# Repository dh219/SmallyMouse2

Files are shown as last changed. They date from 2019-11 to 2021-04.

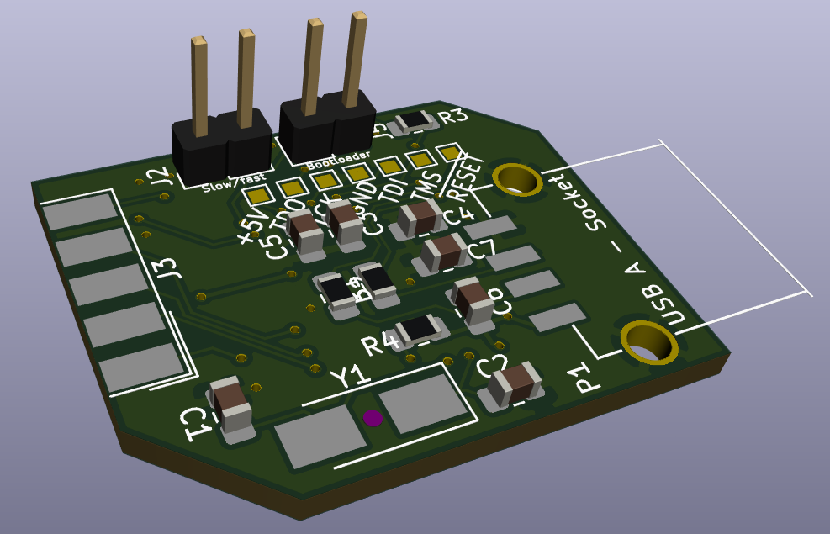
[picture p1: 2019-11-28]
Smalliermouse/images/smallier_board2.png

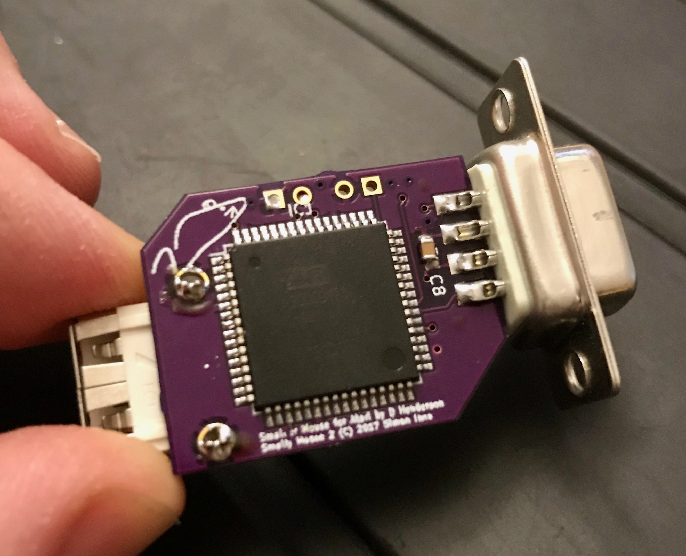
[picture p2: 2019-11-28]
Smalliermouse/images/smallier_complete1.jpg

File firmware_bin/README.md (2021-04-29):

## Binary Firmwares

These firmwares are provided as-is with no warranty or support offered. They may be of use if you don't want, or can't install the (Windows only) Atmel Studio to flash your SmallyMouse variant. They ought to be usable with the AVRDude software, available for many platforms, but please note I HAVE NOT tested this.

## Versions

All versions fix the potentially dangerous (on Atari STs) bug where the AT90 chip drives the button lines high when not in use by switching the lines to input (high-Z) when a button is in the 'up' position.

Low speed movement when a has been greatly enhanced when the DPI Division logic is enabled.

A change of direction lag bug has been fixed upstream.

## Jumper meaning change (from 1.0)

The J2 jumper, which previously set rate limiting on the qudrature output now configures whether the DPI Division logic should be use at all.

J2 connected will divide down the movement of the USB mouse. J2 disconnected will pass though all USB movement directly.

### DPI_DIV_3

This version uses a 1/3 multiplier on each USB mouse movement report to compensate for the much higher DPI rating of modern mice. This ratio is configurable in the firmware by setting the DPISCALE parameter. This parameter indicates the denominator in use. 3 => divide by 3.

### DPI_DIV_2

This version is as above, but uses a 1/2 multiplier.

D Henderson 2021.

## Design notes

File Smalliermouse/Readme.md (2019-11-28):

## Synopsis

Smalliermouse is a variation of SmallyMouse2 by D Henderson specificially designed for the Atari ST & Falcon to fit within the keyboard mouse plug bay.

## Motivation

USB plugs for modern (and particularly wireless) devices are so small theses days that, buy reducing the SmallyMouse2 footprint to its bare minimum would allow the entire mouse emulator to fit within the below-keyboard recess of the Atari ST range of computers.

## Installation

Note: This is an Atmel Studio 7 project that can be loaded and compiled by the IDE

Please see http://www.waitingforfriday.com/?p=827 for detailed documentation about SmallyMouse2

## Author

SmallyMouse2 is written and maintained by Simon Inns. Smalliermouse, upon which it is based remains (C) Simon Inns with modifications by D Henderson 2019.

## License (Software)

    SmallyMouse2 is free software: you can redistribute it and/or modify
    it under the terms of the GNU General Public License as published by
    the Free Software Foundation, either version 3 of the License, or
    (at your option) any later version.

    SmallyMouse2 is distributed in the hope that it will be useful,
    but WITHOUT ANY WARRANTY; without even the implied warranty of
    MERCHANTABILITY or FITNESS FOR A PARTICULAR PURPOSE.  See the
    GNU General Public License for more details.

    You should have received a copy of the GNU General Public License
    along with SmallyMouse2. If not, see <http://www.gnu.org/licenses/>.

## License (Hardware)

Both the schematic and the PCB design of SmallyMouse2 (i.e. the KiCAD project and files) are covered by a Creative Commons license; as with the software you are welcome (and encouraged!) to extend, re-spin and otherwise use and modify the design as allowed by the license.  However; under the terms of the Attribution-ShareAlike 4.0 International (CC BY-SA 4.0) license you are required to release your design (or redesign) under the same license.  For details of the licensing requirements please see <https://creativecommons.org/licenses/by-sa/4.0/>

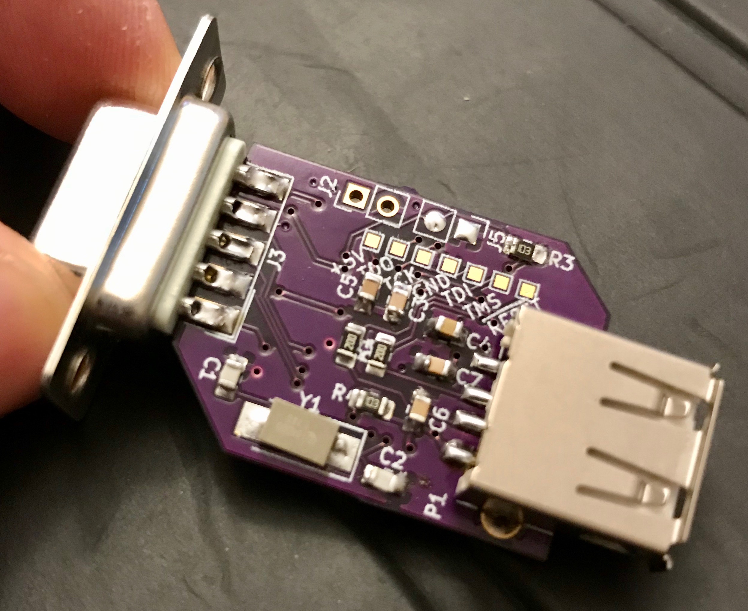
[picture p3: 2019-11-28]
Smalliermouse/images/smallier_complete2.jpg

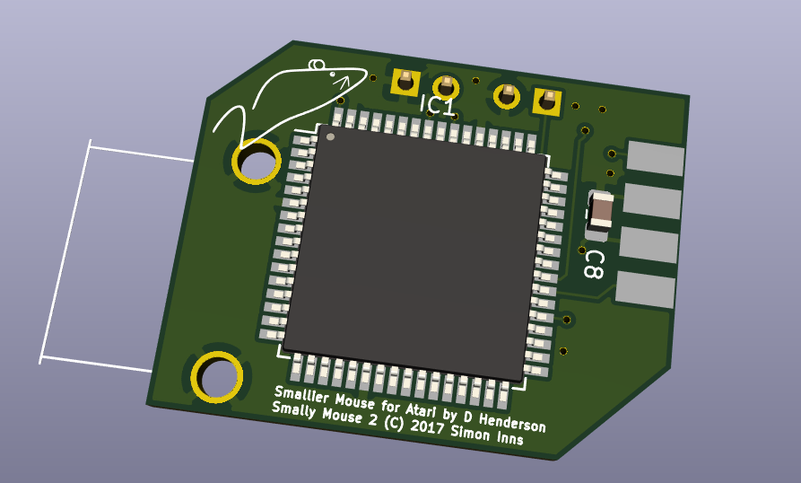
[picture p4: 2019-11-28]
Smalliermouse/images/smallier_board1.png

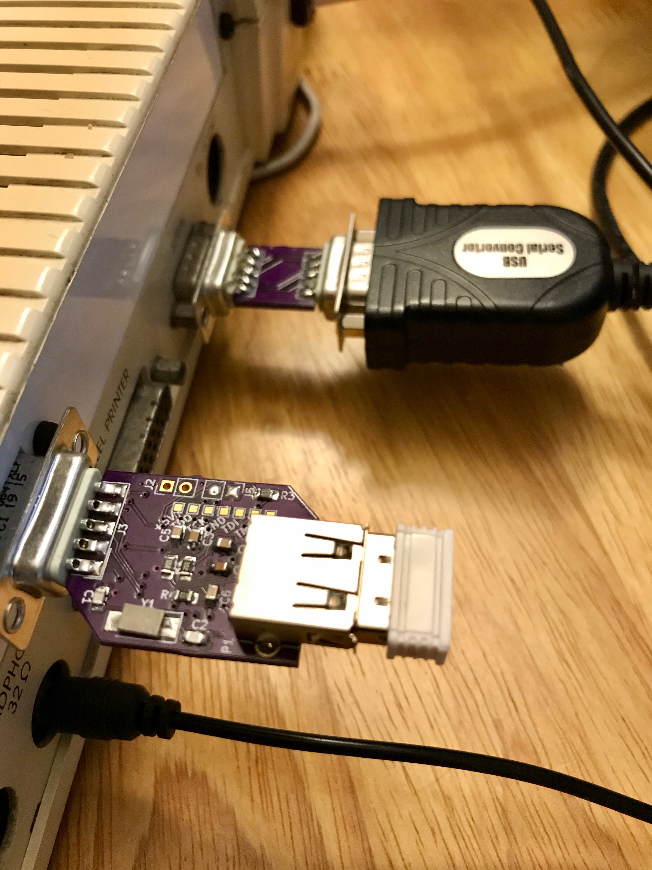
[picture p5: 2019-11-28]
Smalliermouse/images/smallier_insitu_acorn.jpg

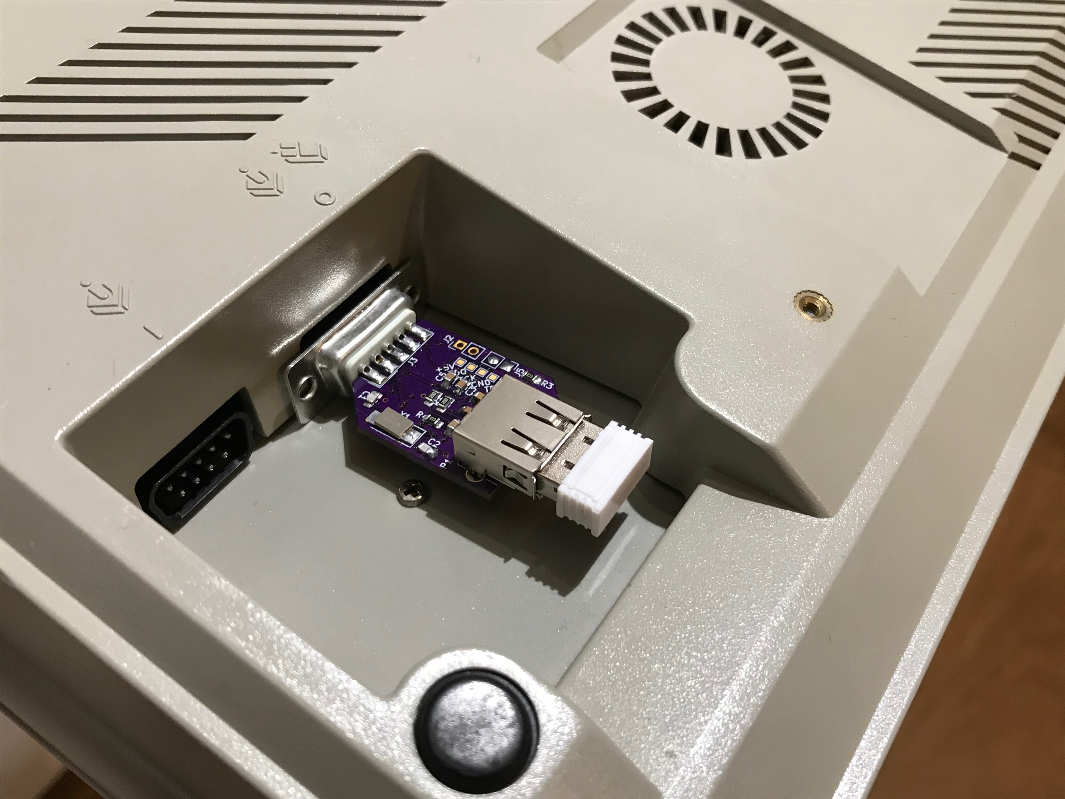
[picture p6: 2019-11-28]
Smalliermouse/images/smallier_insitu_falcon.jpg

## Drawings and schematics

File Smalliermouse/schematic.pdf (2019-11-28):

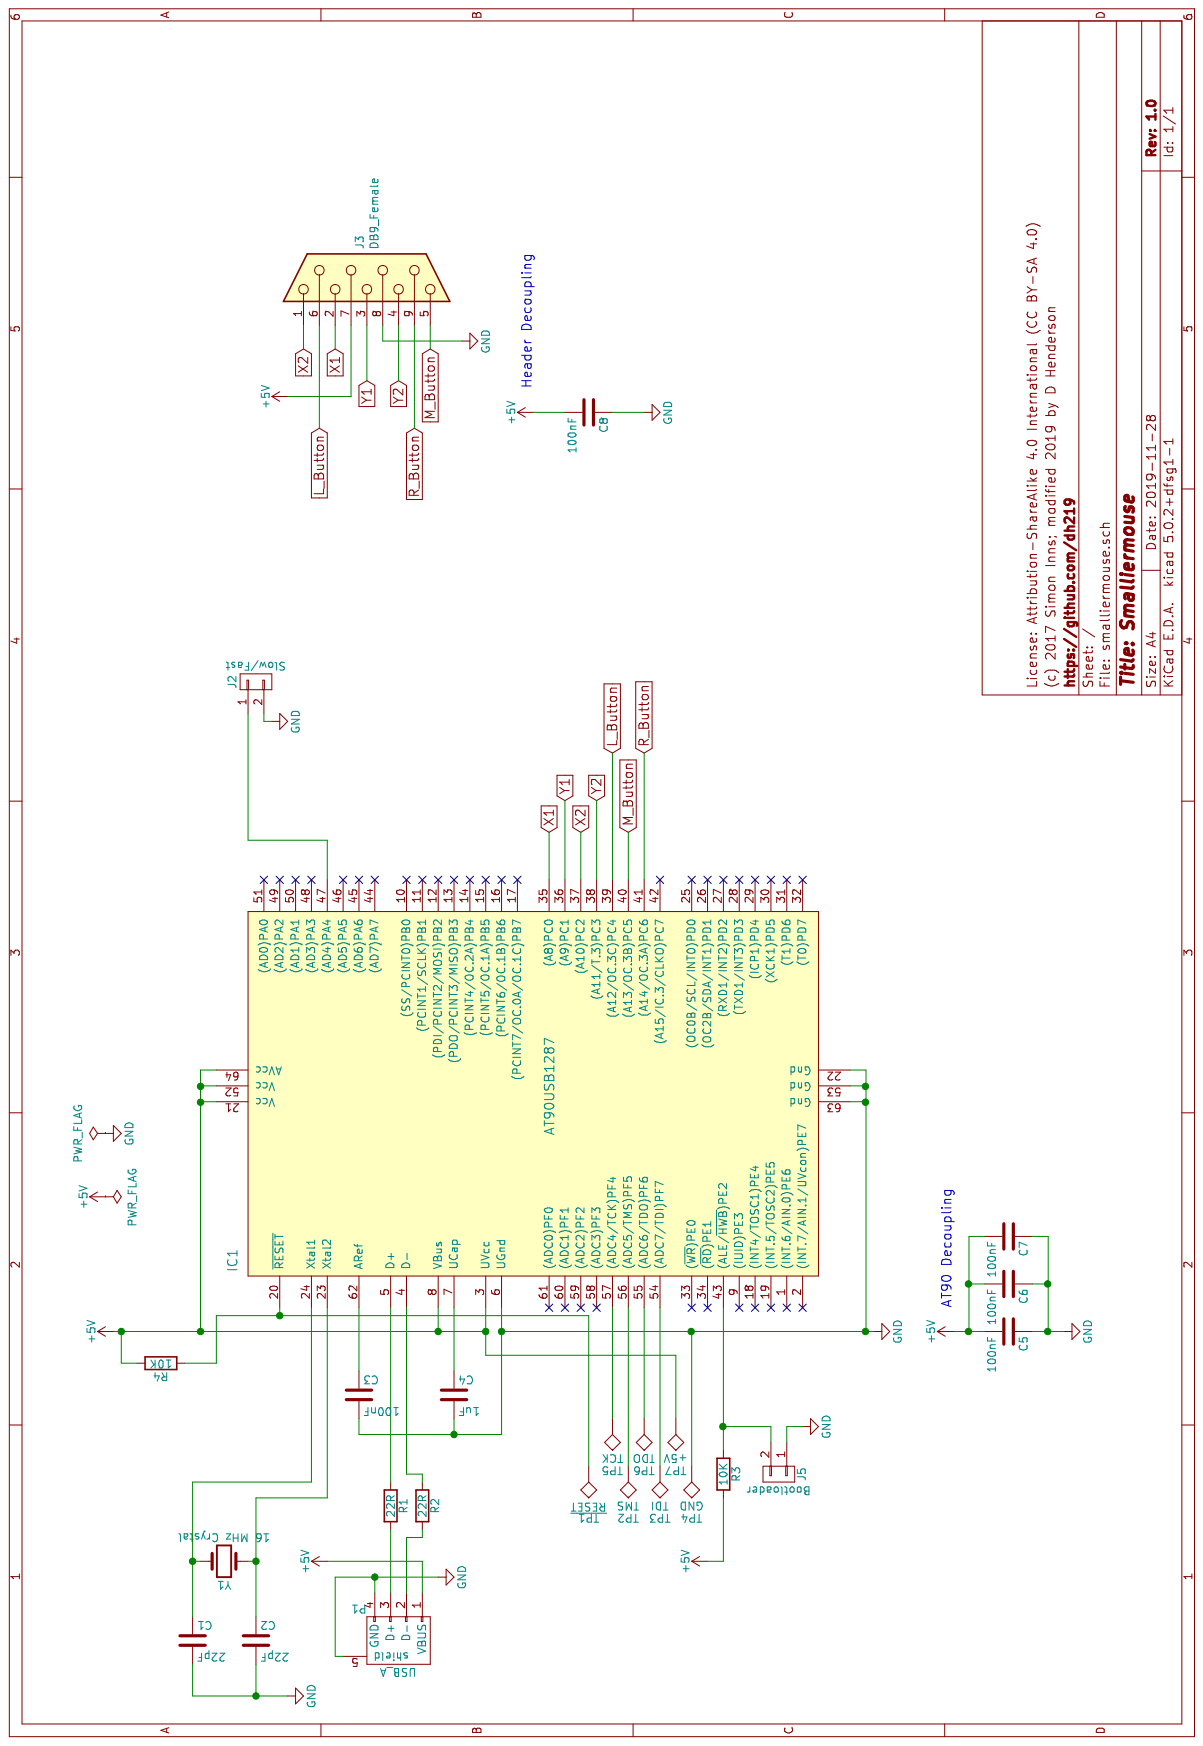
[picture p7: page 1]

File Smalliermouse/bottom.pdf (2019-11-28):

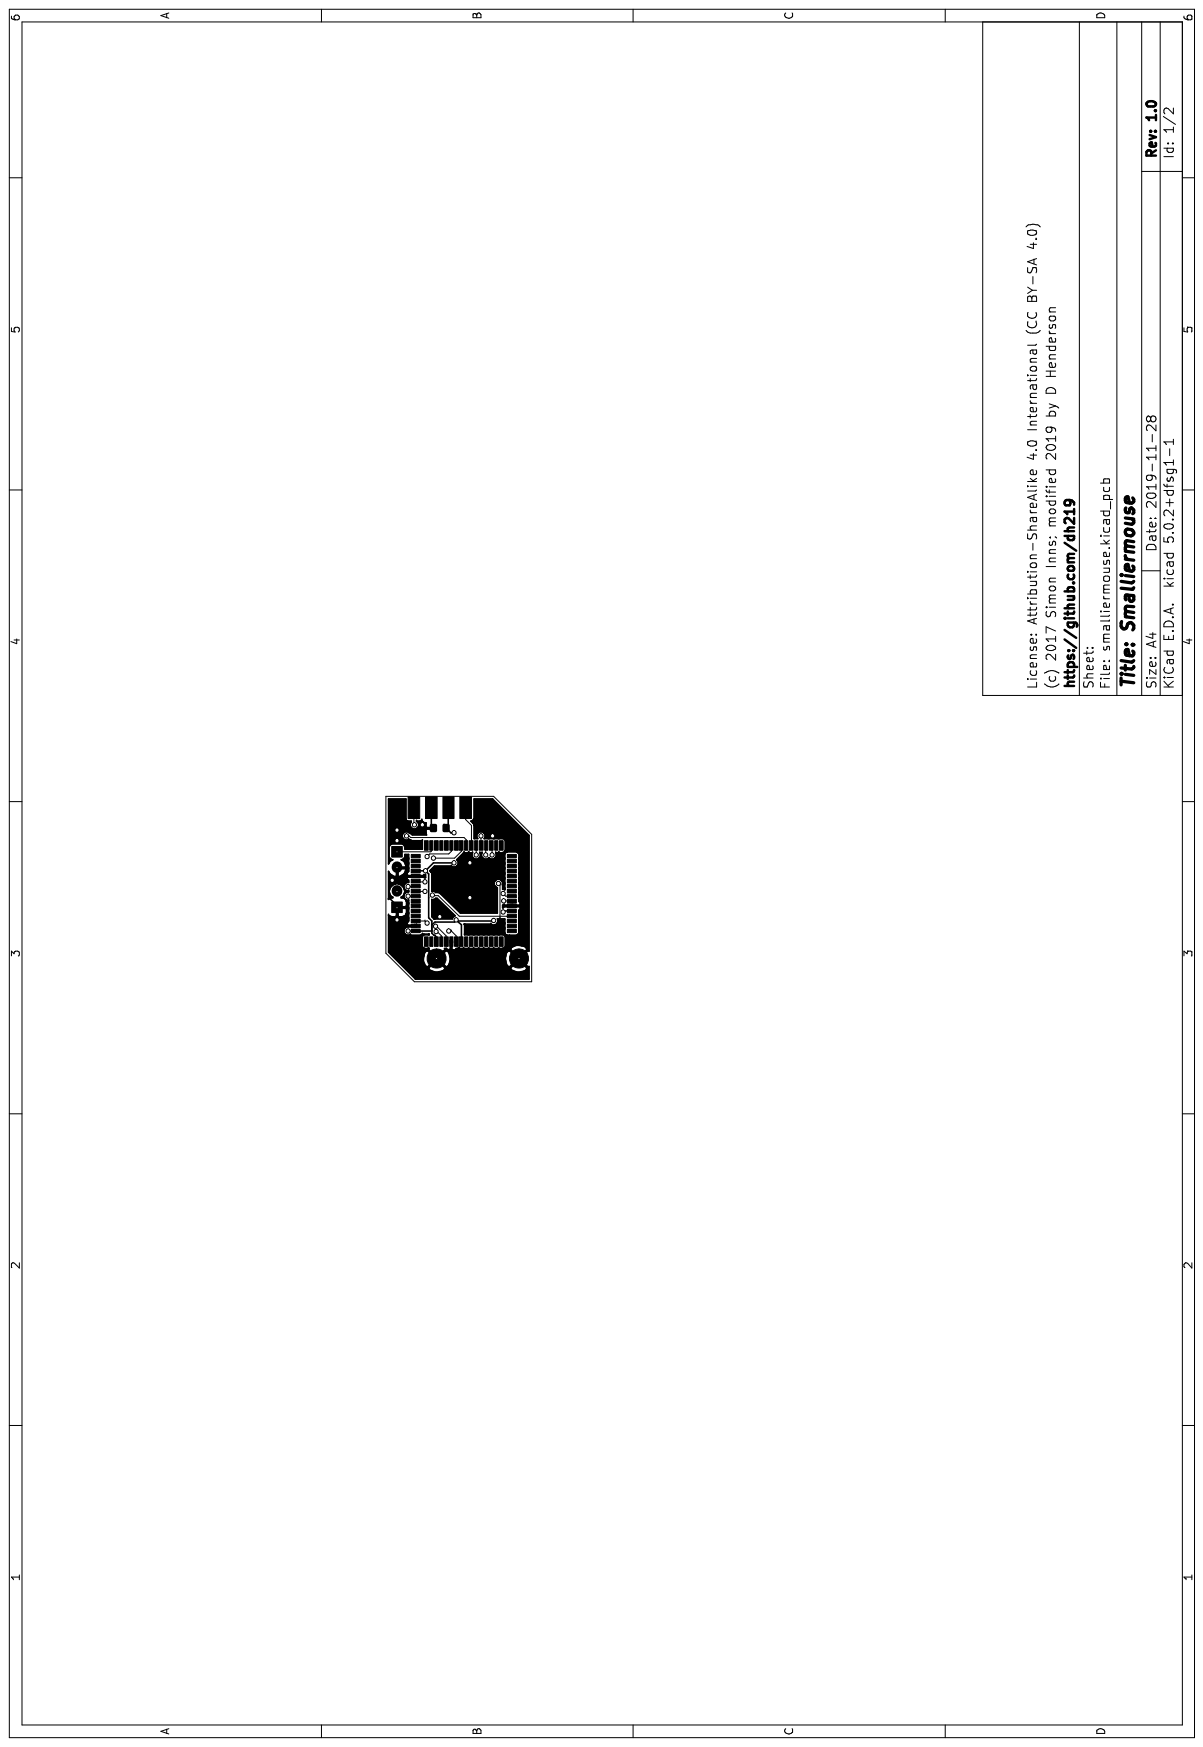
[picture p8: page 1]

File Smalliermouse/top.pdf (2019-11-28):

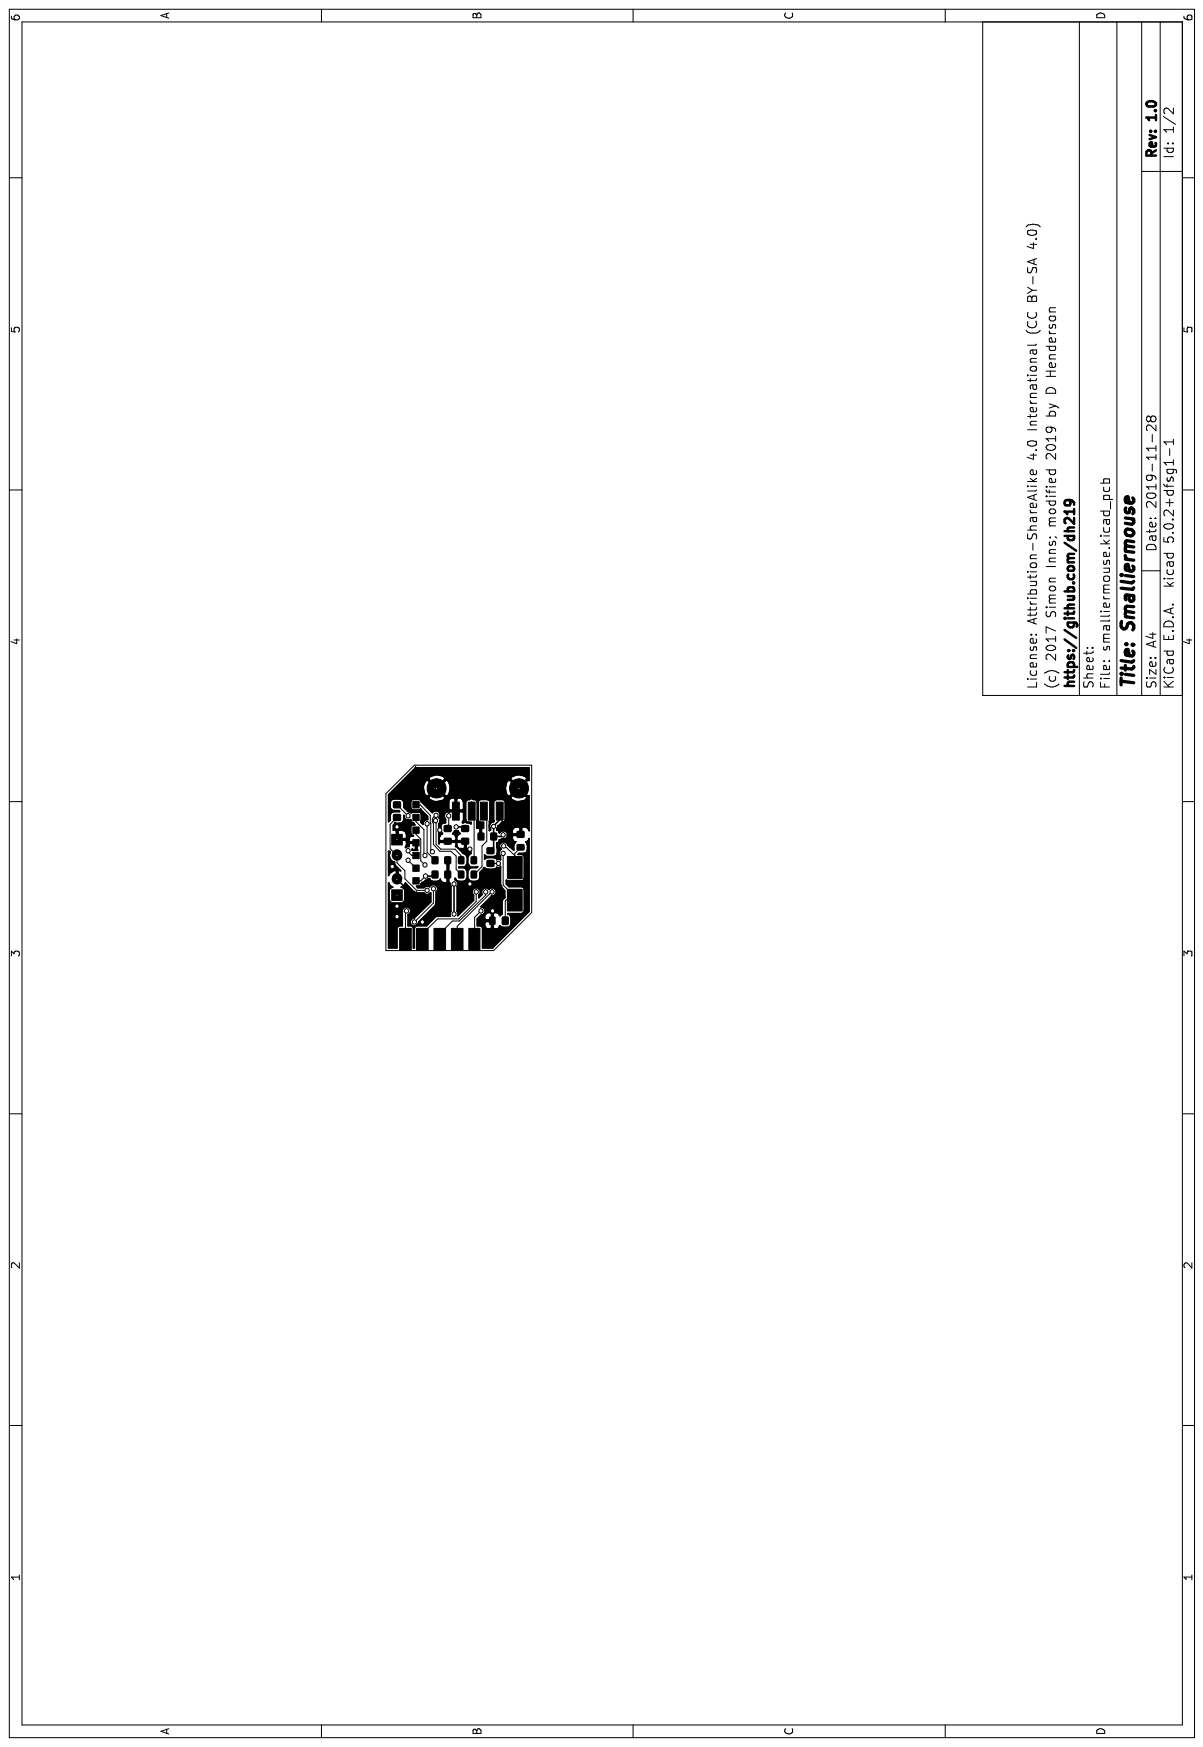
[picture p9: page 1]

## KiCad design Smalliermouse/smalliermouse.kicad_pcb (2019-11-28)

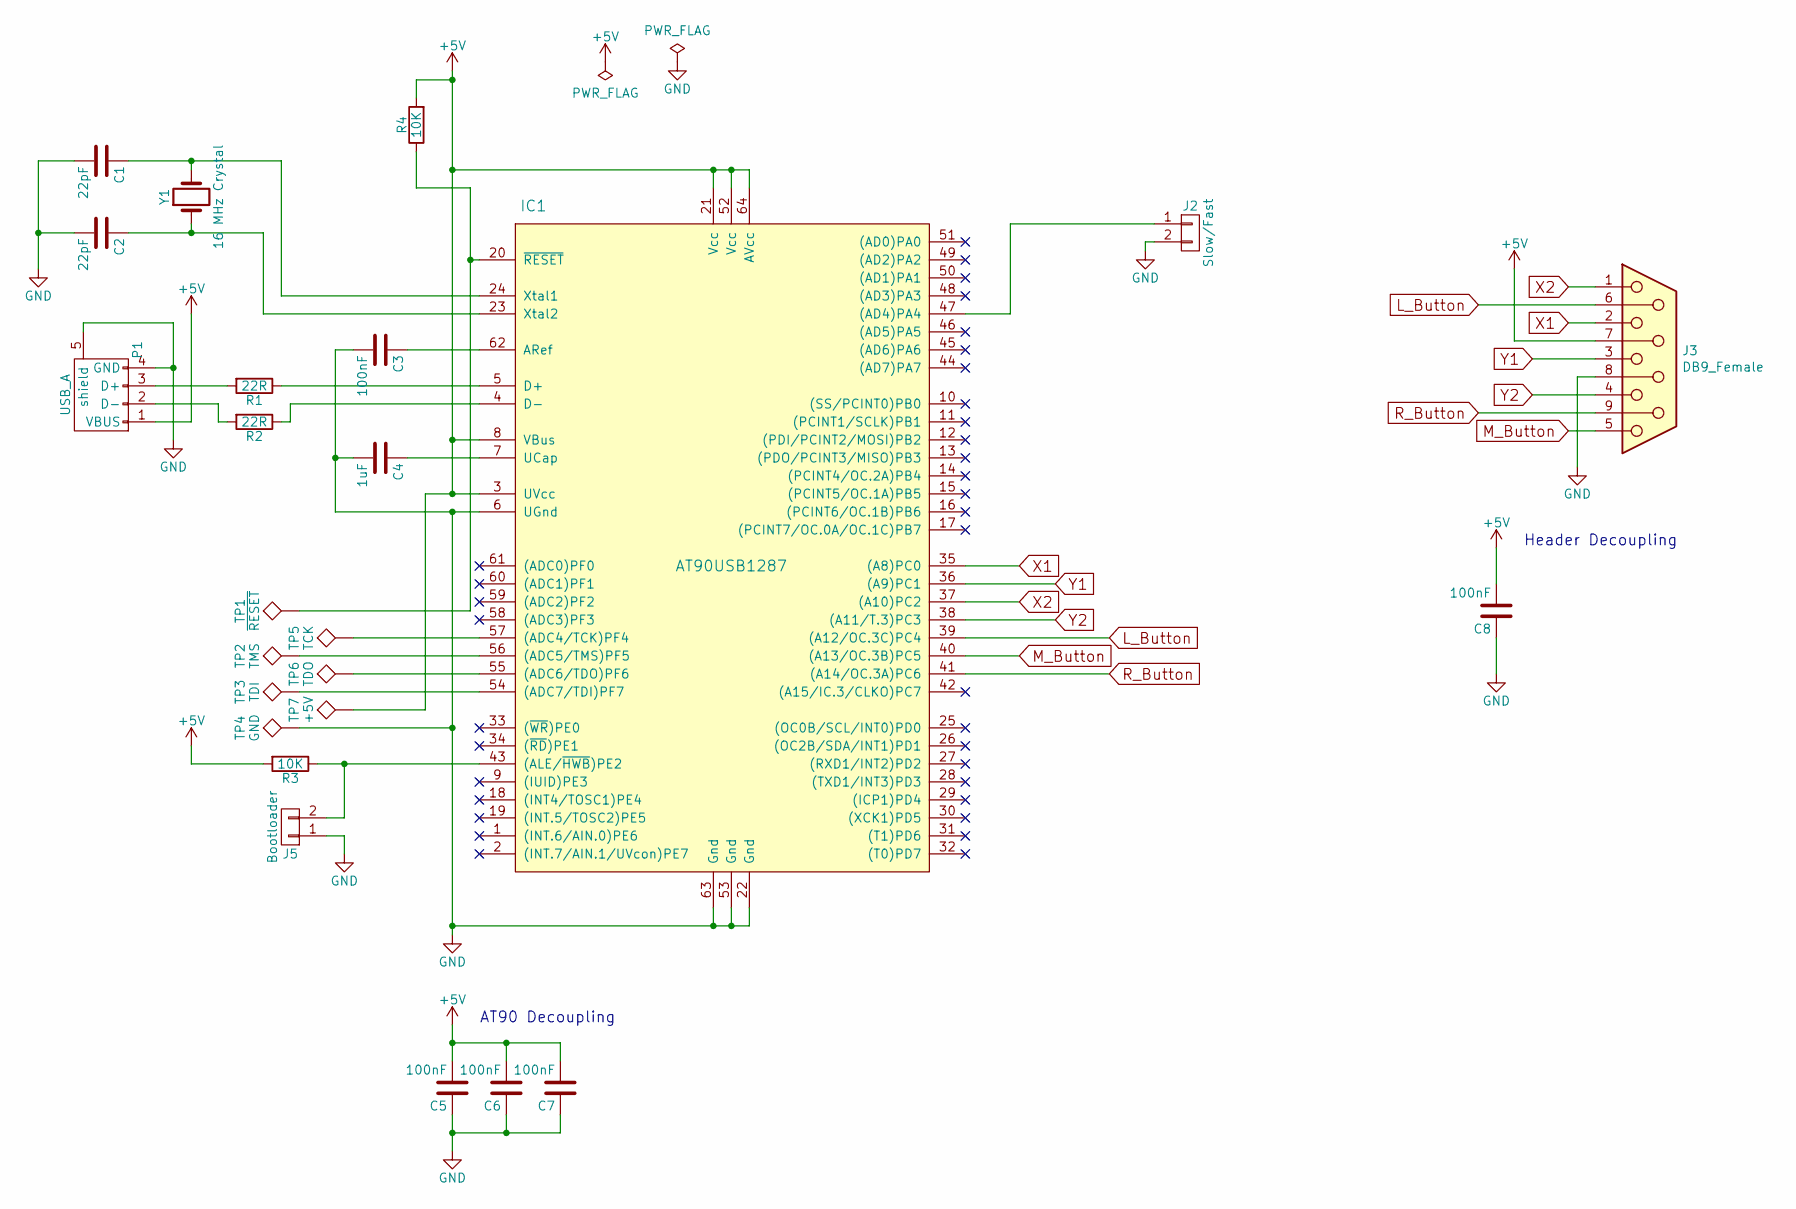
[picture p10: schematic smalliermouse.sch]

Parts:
C1, C2: 22pF; C_0805_2012Metric_Pad1.15x1.40mm_HandSolder
C3, C5, C6, C7, C8: 100nF; C_0805_2012Metric_Pad1.15x1.40mm_HandSolder
C4: 1uF; C_0805_2012Metric_Pad1.15x1.40mm_HandSolder
IC1: AT90USB1287; TQFP-64_14x14mm_P0.8mm
J2: Slow/Fast; PinHeader_1x02_P2.54mm_Vertical
J3: DB9_Female; DSUB-9_Female_EdgeMount_P2.77mm
J5: Bootloader; PinHeader_1x02_P2.54mm_Vertical
P1: USB_A; USB_A_CNCTech_1001-011-01101_Horizontal
R1, R2: 22R; R_0805_2012Metric_Pad1.15x1.40mm_HandSolder
R3, R4: 10K; R_0805_2012Metric_Pad1.15x1.40mm_HandSolder
TP1: ~RESET; TestPoint_Pad_1.0x1.0mm
TP2: TMS; TestPoint_Pad_1.0x1.0mm
TP3: TDI; TestPoint_Pad_1.0x1.0mm
TP4: GND; TestPoint_Pad_1.0x1.0mm
TP5: TCK; TestPoint_Pad_1.0x1.0mm
TP6: TDO; TestPoint_Pad_1.0x1.0mm
TP7: +5V; TestPoint_Pad_1.0x1.0mm
Y1: 16 MHz Crystal; Crystal_SMD_5032-2Pin_5.0x3.2mm_HandSoldering

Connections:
+5V: C5.2, C6.2, C7.2, C8.2, IC1.3 (UVcc), IC1.8 (VBus), IC1.21 (Vcc), IC1.52 (Vcc), IC1.64 (AVcc), J3.7, P1.1 (VBUS), R3.2, R4.2, TP7.1
GND: C1.2, C2.2, C3.2, C4.2, C5.1, C6.1, C7.1, C8.1, IC1.6 (UGnd), IC1.22 (Gnd), IC1.53 (Gnd), IC1.63 (Gnd), J2.2, J3.8, J5.1, P1.4 (GND), P1.5 (shield), TP4.1
L_Button: IC1.39 ((A12/OC.3C)PC4), J3.6
M_Button: IC1.40 ((A13/OC.3B)PC5), J3.5
unnamed: C1.1, IC1.24 (Xtal1), Y1.2
unnamed: C2.1, IC1.23 (Xtal2), Y1.1
unnamed: C3.1, IC1.62 (ARef)
unnamed: C4.1, IC1.7 (UCap)
unnamed: IC1.4 (D-), R2.1
unnamed: IC1.5 (D+), R1.1
unnamed: IC1.20 (~RESET), R4.1, TP1.1
unnamed: IC1.43 ((ALE/~HWB~)PE2), J5.2, R3.1
unnamed: IC1.47 ((AD4)PA4), J2.1
unnamed: IC1.54 ((ADC7/TDI)PF7), TP3.1
unnamed: IC1.55 ((ADC6/TDO)PF6), TP6.1
unnamed: IC1.56 ((ADC5/TMS)PF5), TP2.1
unnamed: IC1.57 ((ADC4/TCK)PF4), TP5.1
unnamed: P1.2 (D-), R2.2
unnamed: P1.3 (D+), R1.2
R_Button: IC1.41 ((A14/OC.3A)PC6), J3.9
X1: IC1.35 ((A8)PC0), J3.2
X2: IC1.37 ((A10)PC2), J3.1
Y1: IC1.36 ((A9)PC1), J3.3
Y2: IC1.38 ((A11/T.3)PC3), J3.4

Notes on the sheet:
AT90 Decoupling
Header Decoupling

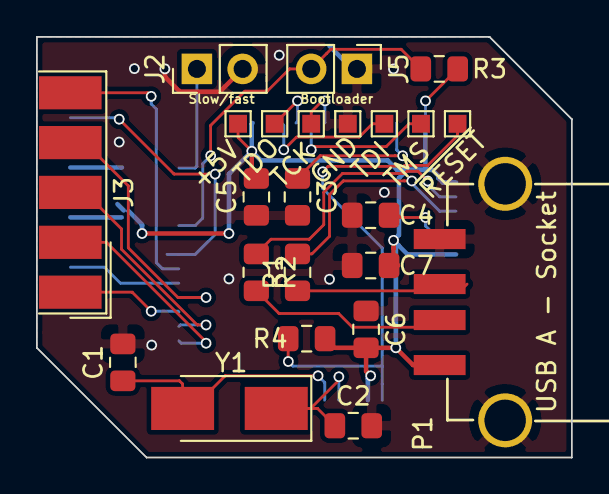
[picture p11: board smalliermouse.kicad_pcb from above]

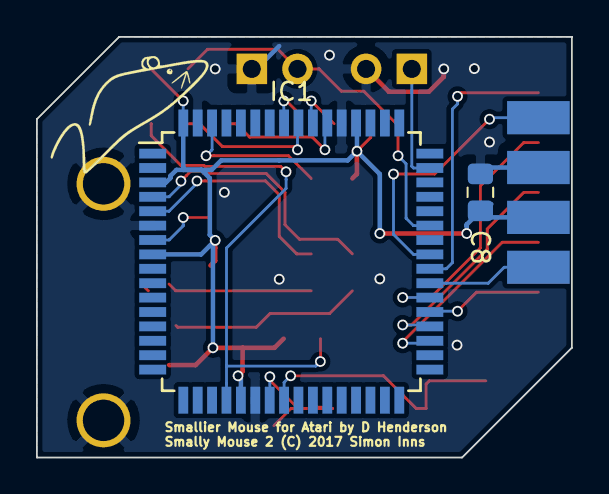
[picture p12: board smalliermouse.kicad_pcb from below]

Board: 2 copper layers, 29.7 x 23.4 mm, 25 parts (2 on the bottom side), 24 nets.

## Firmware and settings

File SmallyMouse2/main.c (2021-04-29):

/************************************************************************
	main.c

	Main functions
    SmallyMouse2 - USB to quadrature mouse converter
    Copyright (C) 2017-2020 Simon Inns

	This file is part of SmallyMouse2.

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
	Email: simon.inns@gmail.com

************************************************************************/

// Important notice:  If you port this firmware to another hardware design
// it *will be* a derivative of the original and therefore you must pay attention
// to the CC hardware licensing and release your hardware design as per the share-
// alike license.  Keep it open! ...and yes, that includes you Commodore chaps.

// System includes
#include <avr/io.h>
#include <avr/wdt.h>
#include <avr/pgmspace.h>
#include <avr/interrupt.h>
#include <avr/power.h>
#include <stdio.h>
#include <stdlib.h>

#include <util/delay.h>

// Note: SmallyMouse2 makes extensive use of the LUFA libraries:
//
// LUFA Library
// Copyright (C) Dean Camera, 2015.
// dean [at] fourwalledcubicle [dot] com
// www.lufa-lib.org

// Include LUFA libraries
#include <LUFA/Drivers/Misc/TerminalCodes.h>
#include <LUFA/Drivers/USB/USB.h>
#include <LUFA/Drivers/Peripheral/Serial.h>
#include <LUFA/Platform/Platform.h>

#include "ConfigDescriptor.h"
#include "main.h"

#define MOUSEX	0
#define MOUSEY	1

// Configuration ------------------------------------------------------------------------------------------------------

// Quadrature output frequency limit
//
// This setting limits the maximum frequency of the quadrature output towards the retro computer.
// If the rate of output is too high the retro computer cannot 'count' the input accurately and
// this causes spurious mouse movement.
//
// With no rate limit the quadrature output speed will reach a maximum of 3,906.25 Hz
// For 8-bit machines it is recommended that the speed doesn't exceed 500 Hz.  This limit is
// only applied if the 'slow' configuration jumper is shorted (i.e. on)
#define Q_RATELIMIT 400

// Quadrature output buffer limit
//
// Since the slow rate limit will prevent the quadrature output keeping up with the USB movement
// report input, the quadrature output will lag behind (i.e. the quadrature mouse will continue
// to move after the USB mouse has stopped).  This setting limits the maximum number of buffered
// movements to the quadrature output.  If the buffer reaches this value further USB movements
// will be discarded
#define Q_BUFFERLIMIT 100

// DPI Divider
//
// Some USB mice have very high DPI which causes the quadrature rate to be too high (making the
// mouse move too fast).  If the DPISW header is shorted the following constant will be used to 
// divide the DPI rate to slow things down.  2 or 3 are reasonable values.
#define DPI_DIVIDER 3

// Interrupt Service Routines for quadrature output -------------------------------------------------------------------

// The following globals are used by the interrupt service routines to track the mouse
// movement.  The mouseDirection indicates which direction the mouse is moving in and
// the mouseEncoderPhase tracks the current phase of the quadrature output.
//
// The mouseDistance variable tracks the current distance the mouse has left to move
// (this is incremented by the USB mouse reports and decremented by the ISRs as they
// output the quadrature to the retro host).
volatile int8_t mouseDirectionX = 0;		// X direction (0 = decrement, 1 = increment)
volatile int8_t mouseEncoderPhaseX = 0;		// X Quadrature phase (0-3)

volatile int8_t mouseDirectionY = 0;		// Y direction (0 = decrement, 1 = increment)
volatile int8_t mouseEncoderPhaseY = 0;		// Y Quadrature phase (0-3)

volatile int16_t mouseDistanceX = 0;		// Distance left for mouse to move
volatile int16_t mouseDistanceY = 0;		// Distance left for mouse to move

volatile uint8_t xTimerTop = 0;				// X axis timer TOP value
volatile uint8_t yTimerTop = 0;				// Y axis timer TOP value

// Interrupt Service Routine based on Timer0 for mouse X movement quadrature output
ISR(TIMER0_COMPA_vect)
{
	// Process X output
	if (mouseDistanceX > 0) {
		// Change phase and range check
		if (mouseDirectionX == 0) {
			mouseEncoderPhaseX--;
			if (mouseEncoderPhaseX < 0) mouseEncoderPhaseX = 3;
			} else {
			mouseEncoderPhaseX++;
			if (mouseEncoderPhaseX > 3) mouseEncoderPhaseX = 0;
		}
		
		// Set the output pins according to the current phase
		if (mouseEncoderPhaseX == 0) X1_PORT |=  X1;	// Set X1 to 1
		if (mouseEncoderPhaseX == 1) X2_PORT |=  X2;	// Set X2 to 1
		if (mouseEncoderPhaseX == 2) X1_PORT &= ~X1;	// Set X1 to 0
		if (mouseEncoderPhaseX == 3) X2_PORT &= ~X2;	// Set X2 to 0
		
		// Decrement the distance left to move
		mouseDistanceX--;
	}
	
	// Set the timer top value for the next interrupt
	OCR0A = xTimerTop;
}

// Interrupt Service Routine based on Timer2 for mouse Y movement quadrature output
ISR(TIMER2_COMPA_vect)
{
	// Process Y output
	if (mouseDistanceY > 0) {
		// Change phase and range check
		if (mouseDirectionY == 0) {
			mouseEncoderPhaseY--;
			if (mouseEncoderPhaseY < 0) mouseEncoderPhaseY = 3;
			} else {
			mouseEncoderPhaseY++;
			if (mouseEncoderPhaseY > 3) mouseEncoderPhaseY = 0;
		}
				
		// Set the output pins according to the current phase
		if (mouseEncoderPhaseY == 3) Y1_PORT &= ~Y1;	// Set Y1 to 0
		if (mouseEncoderPhaseY == 2) Y2_PORT &= ~Y2;	// Set Y2 to 0
		if (mouseEncoderPhaseY == 1) Y1_PORT |=  Y1;	// Set Y1 to 1
		if (mouseEncoderPhaseY == 0) Y2_PORT |=  Y2;	// Set Y2 to 1

		// Decrement the distance left to move
		mouseDistanceY--;
	}
	
	// Set the timer top value for the next interrupt
	OCR2A = yTimerTop;
}

// Main function
int main(void)
{
	// Initialise the SmallyMouse2 hardware
	initialiseHardware();
	
	// Initialise the ISR timers
	initialiseTimers();

	// Enable interrupts (required for USB support and quadrature output ISRs)
	sei();
	
	// Main processing loop
	while(1) {
		// Perform any pending mouse actions
		processMouse();

		// Process the USB host interface
		USB_USBTask();
	}
}

// Initialise the SmallyMouse2 hardware
void initialiseHardware(void)
{
	// Disable the watchdog timer (if set in fuses)
	MCUSR &= ~(1 << WDRF);
	wdt_disable();

	// Disable the clock divider (if set in fuses)
	clock_prescale_set(clock_div_1);

	// Set the quadrature output pins to output
	X1_DDR |= X1; // Output
	X2_DDR |= X2; // Output
	Y1_DDR |= Y1; // Output
	Y2_DDR |= Y2; // Output
	
	// Set quadrature output pins to zero
	X1_PORT &= ~X1; // Pin = 0
	X2_PORT &= ~X2; // Pin = 0
	Y1_PORT &= ~Y1; // Pin = 0
	Y2_PORT &= ~Y2; // Pin = 0
	
	// Set mouse button output pins open drain
	// (solves issues with some retro machines that
	// don't like 5V to be sources from the pins)
	LB_DDR &= ~LB; // 0 = input
	MB_DDR &= ~MB; // 0 = input
	RB_DDR &= ~RB; // 0 = input
	LB_PORT &= ~LB; // Pin = 0 (off)
	MB_PORT &= ~MB; // Pin = 0 (off)
	RB_PORT &= ~RB; // Pin = 0 (off)

	// Set the rate limit configuration header to input
	RATESW_DDR &= ~RATESW; // Input
	RATESW_PORT |= RATESW; // Turn on weak pull-up
	
	// Configure E7 on the expansion header to act as
	// DPISW (since it is easily jumpered to 0V)	
	DPISW_DDR &= ~DPISW; // Input
	DPISW_PORT |= DPISW; // Turn on weak pull-up
	
	// Initialise the expansion (Ian) header
	E0_DDR |= ~E0; // Output
	E1_DDR |= ~E1; // Output
	E2_DDR |= ~E2; // Output
	E3_DDR |= ~E3; // Output
	E4_DDR |= ~E4; // Output
	E5_DDR |= ~E5; // Output
	E6_DDR |= ~E6; // Output
	
	E0_PORT &= ~E0; // Pin = 0
	E1_PORT &= ~E1; // Pin = 0
	E2_PORT &= ~E2; // Pin = 0
	E3_PORT &= ~E3; // Pin = 0
	E4_PORT &= ~E4; // Pin = 0
	E5_PORT &= ~E5; // Pin = 0
	E6_PORT &= ~E6; // Pin = 0
	
	// Initialise the LUFA USB stack
	USB_Init();
	
	// By default, SmallyMouse2 will output USB debug events on the 
	// AVR's UART port.  You can monitor the debug console by connecting
	// a serial to USB adapter.  Only the Tx (D3 and 0V pins are required).
	
	// Initialise the serial UART - 9600 baud 8N1
	Serial_Init(9600, false);

	// Create a serial debug stream on stdio
	// Note: The serial UART is available on the 
	// expansion (Ian) header
	Serial_CreateStream(NULL);

	// Output some debug header information to the serial console
	puts_P(PSTR(ESC_FG_YELLOW "SmallyMouse2 V1.3 - Serial debug console\r\n" ESC_FG_WHITE));
	puts_P(PSTR(ESC_FG_YELLOW "(c)2017-2020 Simon Inns\r\n" ESC_FG_WHITE));
	puts_P(PSTR(ESC_FG_YELLOW "http://www.waitingforfriday.com\r\n" ESC_FG_WHITE));
	
	// Now report the status of the various configuration switches
	if ((RATESW_PIN & RATESW) == 0) puts_P(PSTR("Rate limit switch is ON\r\n"));
	else puts_P(PSTR("Rate limit switch is OFF\r\n"));
	if ((DPISW_PIN & DPISW) == 0) puts_P(PSTR("DPI divide switch is ON\r\n"));
	else puts_P(PSTR("DPI divide switch is OFF\r\n"));
}

// Initialise the ISR timers
void initialiseTimers(void)
{
	// The frequency of the reports from the USB mouse is about 100-125 Hz (i.e.
	// 100-125 reports per second).  Each report can indicate up to 127 position
	// movements in each direction (X & Y)
	
	// If we can receive 127 movements per report at a rate of 125 Hz
	// then the maximum movement per second is 100-125 Hz * 127 movements =
	// 12,700 - 15,875 movements per second (i.e. the quadrature output has 
	// to be 12,700 - 15,875 Hz to keep up)
	
	// The setting of the timers controls the maximum interrupt speed and 
	// therefore the maximum possible quadrature rate output.
	// 
	// Each movement unit reported by the USB device causes a single phase
	// change in the quadrature output (which means there is a 4:1 ratio
	// between the USB movement units and the quadrature movement output)
	
	// Timer0 and Timer2 are 8-bit timers.  Therefore the slowest interrupt
	// speed possible is 256 times the tick period and the fastest is a single
	// tick period.
	
	// Timer prescale is /1024 and the AVR clock speed is 16,000,000 Hz
	// 16,000,000 Hz / 1024 prescale = 15,625 ticks per second
	//
	// 1,000,000 uS per second / 15,625 ticks per second = 64 uS per tick
	//
	// 15,625 ticks (with a 4:1 ratio) means the maximum quadrature output
	// will be 3,906.25 Hz.

	// Configure Timer0 to interrupt (8-bit timer)
	OCR0A = 0; // In CTC mode OCR0A = TOP
	TCCR0A = (1 << WGM01); // Clear timer on compare match (CTC) mode
	TCCR0B = 5; //  CS02/CS01/CS00 = binary 101 = /1024 prescale
	TIMSK0 = (1 << OCIE0A); // Timer0 interrupt enabled
		
	// Configure Timer2 to interrupt (8-bit timer)
	OCR2A = 0; // In CTC mode OCR2A = TOP
	TCCR2A = (1 << WGM21); // Clear timer on compare match (CTC) mode
	TCCR2B = 7; // CS22/CS21/CS20 = binary 111 = /1024 prescale
	TIMSK2 = (1 << OCIE2A); // Timer2 interrupt enabled
}

// Read the mouse USB report and process the information
void processMouse(void)
{
	USB_MouseReport_Data_t MouseReport;
	bool limitRate = true;
	bool dpiDivide = false;
		
	// Only process the mouse if a mouse is attached to the USB port
	if (USB_HostState != HOST_STATE_Configured)	return;
	
	// Get the state of the rate limiting (slow) header
	if ((RATESW_PIN & RATESW) == 0) limitRate = false;
	
	// Get the state of the DPI divider header
	if ((DPISW_PIN & DPISW) == 0) dpiDivide = true;
	
	// Select mouse data pipe
	Pipe_SelectPipe(MOUSE_DATA_IN_PIPE);

	// Unfreeze mouse data pipe
	Pipe_Unfreeze();

	// Has a packet arrived from the USB device?
	if (!(Pipe_IsINReceived())) {
		// Nothing received, exit...
		Pipe_Freeze();
		return;
	}

	// Ensure pipe is in the correct state before reading
	if (Pipe_IsReadWriteAllowed()) {
		// Set USB report processing activity on expansion port pin D0
		// Note: This can be used to analyze the rate at which USB mouse
		// reports are received by measuring the rate using an oscilloscope
		// or frequency counter on D0
		E0_PORT |= E0; // Pin = 1
		
		// Read in mouse report data
		Pipe_Read_Stream_LE(&MouseReport, sizeof(MouseReport), NULL);
		
		// The USB mouse report contains 3 variables: button, X and Y
		//
		// Button is an 8-bit flag containing up to 5 button states:
		//   (LSB)1 = Left button
		//        2 = Right button
		//        4 = Middle button
		//
		// Note: Buttons are active low (i.e. 0 = pressed)
		//
		// X and Y indicate the number of steps the mouse moved since the
		// last report was sent.
		//
		// +X = Mouse going right
		// -X = Mouse going left
		// +Y = Mouse going down
		// -Y = Mouse going up
		//
		// X and Y have a range of -127 to +127
		
		// If the mouse movement changes X direction then disregard any remaining movement
		if (MouseReport.X > 0 && mouseDirectionX == 0) {
			mouseDistanceX = 0;
			mouseDirectionX = 1;
		} else if (MouseReport.X < 0 && mouseDirectionX == 1) {
			mouseDistanceX = 0;
			mouseDirectionX = 0;
		}
		
		// If the mouse movement changes Y direction then disregard any remaining movement
		if (MouseReport.Y > 0 && mouseDirectionY == 0) {
			mouseDistanceY = 0;
			mouseDirectionY = 1;
			} else if (MouseReport.Y < 0 && mouseDirectionY == 1) {
			mouseDistanceY = 0;
			mouseDirectionY = 0;
		}
		
		// Process mouse X and Y movement -------------------------------------
		xTimerTop = processMouseMovement(MouseReport.X, MOUSEX, limitRate, dpiDivide);
		yTimerTop = processMouseMovement(MouseReport.Y, MOUSEY, limitRate, dpiDivide);
		
		// Process mouse buttons ----------------------------------------------
		
		// Check for left mouse button
		if ((MouseReport.Button & 0x01) == 0) {
			// Open-drain
			LB_PORT &= ~LB;
			LB_DDR &= ~LB;
		} else {
			// Set to 0V
			LB_DDR |= LB; // 1 = output
			LB_PORT &= ~LB; // Button low
		}
			
		// Check for middle mouse button
		if ((MouseReport.Button & 0x04) == 0) {
			// Open-drain
			MB_PORT &= ~MB;
			MB_DDR &= ~MB;
		} else {
			// Set to 0V
			MB_DDR |= MB; // 1 = output
			MB_PORT &= ~MB; // Button low
		}
			
		// Check for right mouse button
		if ((MouseReport.Button & 0x02) == 0) {
			// Open-drain
			RB_PORT &= ~RB;
			RB_DDR &= ~RB;
		} else {
			// Set to 0V
			RB_DDR |= RB; // 1 = output
			RB_PORT &= ~RB; // Button low
		}
		
		// Clear USB report processing activity on expansion port pin D0
		E0_PORT &= ~E0; // Pin = 0
	}

	// Clear the IN endpoint, ready for next data packet
	Pipe_ClearIN();

	// Refreeze mouse data pipe
	Pipe_Freeze();
}

// Process the mouse movement units from the USB report
uint8_t processMouseMovement(int8_t movementUnits, uint8_t axis, bool limitRate, bool dpiDivide)
{
	uint16_t timerTopValue = 0;
	static int8_t skippedunits[2] = {0,0};

	// Set the mouse movement direction and record the movement units
	if (movementUnits > 0) {
		// Moving in the positive direction
		
		// Apply DPI limiting if required
		if (dpiDivide) {
			movementUnits /= DPI_DIVIDER;
//			if (movementUnits < 1) movementUnits = 1;

			// avoid inverse mouse acceleration effect where slow movement is at full DPI -- dh219
			if( movementUnits == 0  ) {// has been scaled away to zero
				if( skippedunits[axis] >= DPI_DIVIDER ) {
					movementUnits = 1;
					skippedunits[axis] = 0;
				}
				else {
					if( skippedunits[axis] < 0 ) {
						skippedunits[axis] = 0;
					}
					skippedunits[axis]++;
				}
			}


		}
		
		// Add the movement units to the quadrature output buffer
		if (axis == MOUSEX) mouseDistanceX += movementUnits;
		else mouseDistanceY += movementUnits;
	} else if (movementUnits < 0) {
		// Moving in the negative direction
		
		// Apply DPI limiting if required
		if (dpiDivide) {
			movementUnits /= DPI_DIVIDER;
//			if (movementUnits > -1) movementUnits = -1;

			// avoid inverse mouse acceleration effect where slow movement is at full DPI -- dh219
			if( movementUnits == 0  ) {// has been scaled away to zero
				if( skippedunits[axis] <= -DPI_DIVIDER ) {
					movementUnits = -1;
					skippedunits[axis] = 0;
				}
				else {
					if( skippedunits[axis] > 0 ) {
						skippedunits[axis] = 0;
					}
					skippedunits[axis]--;
				}
			}
		}
		
		// Add the movement units to the quadrature output buffer
		if (axis == MOUSEX) mouseDistanceX += -movementUnits;
		else mouseDistanceY += -movementUnits;
	} else {
		if (axis == MOUSEX) mouseDistanceX = 0;
		else mouseDistanceY = 0;
	}
	
	// Apply the quadrature output buffer limit
	if (axis == MOUSEX) {
		if (mouseDistanceX > Q_BUFFERLIMIT) mouseDistanceX = Q_BUFFERLIMIT;
	} else {
		if (mouseDistanceY > Q_BUFFERLIMIT) mouseDistanceY = Q_BUFFERLIMIT;
	}
	
	// Get the current value of the quadrature output buffer
	if (axis == MOUSEX) timerTopValue = mouseDistanceX;
	else timerTopValue = mouseDistanceY;
	
	// Range check the quadrature output buffer
	if (timerTopValue > 127) timerTopValue = 127;
	
	// Since the USB reports arrive at 100-125 Hz (even if there is only
	// a small amount of movement, we have to output the quadrature
	// at minimum rate to keep up with the reports (otherwise it creates
	// a slow lag).  If we assume 100 Hz of reports then the following
	// is true:
	//
	// 127 movements = 12,700 interrupts/sec
	// 100 movements = 10,000 interrupts/sec
	//  50 movements =  5,000 interrupts/sec
	//  10 movements =  1,000 interrupts/sec
	//   1 movement  =    100 interrupts/sec
	//
	// Timer speed is 15,625 ticks per second = 64 uS per tick
	//
	// Required timer TOP values (0 is fastest so all results are x-1):
	// 1,000,000 / 12,700 = 78.74 / 64 uS = 1.2 - 1
	// 1,000,000 / 10,000 = 100 / 64 uS = 1.56 - 1
	// 1,000,000 / 5,000 = 200 / 64 uS = 3.125 - 1
	// 1,000,000 / 1,000 = 1000 uS / 64 uS = 15.63 - 1
	// 1,000,000 / 100 = 10000 uS / 64 uS = 156.25 - 1
	//
	// So:
	//   timerTopValue = 10000 / timerTopValue; // i.e. 1,000,000 / (timerTopValue * 100)
	//   timerTopValue = timerTopValue / 64;
	//   timerTopValue = timerTopValue - 1;
	
	if (timerTopValue > 0) timerTopValue = ((10000 / timerTopValue) / 64) - 1;
	else timerTopValue = 0; // Avoid divide by zero
		
	// If the 'Slow' configuration jumper is shorted; apply the quadrature rate limit
	if (limitRate) {
		// Rate limit is on
		
		// Rate limit is provided in hertz
		// Each timer tick is 64 uS
		//
		// Convert hertz into period in uS
		// 1500 Hz = 1,000,000 / 1500 = 666.67 uS
		// 
		// Convert period into timer ticks (* 4 due to quadrature)
		// 666.67 us / (64 * 4) = 2.6 ticks
		//
		// Timer TOP is 0-255, so subtract 1
		// 10.42 ticks - 1 = 9.42 ticks
		
		uint32_t rateLimit = ((1000000 / Q_RATELIMIT) / 256) - 1;
		
		// If the timerTopValue is less than the rate limit, we output
		// at the maximum allowed rate.  This will cause addition lag that
		// is handled by the quadrature output buffer limit above.
		if (timerTopValue < (uint16_t)rateLimit) timerTopValue = (uint16_t)rateLimit;
	}
	
	// Return the timer TOP value
	return (uint8_t)timerTopValue;
}

// LUFA event handlers ------------------------------------------------------------------------------------------------

// Event handler for the USB_DeviceAttached event. This indicates that a device has been attached to the host, and
// starts the library USB task to begin the enumeration and USB management process.
void EVENT_USB_Host_DeviceAttached(void)
{
	puts_P(PSTR(ESC_FG_GREEN "USB Device attached\r\n" ESC_FG_WHITE));
}

// Event handler for the USB_DeviceUnattached event. This indicates that a device has been removed from the host, and
// stops the library USB task management process.
void EVENT_USB_Host_DeviceUnattached(void)
{
	puts_P(PSTR(ESC_FG_GREEN "USB Device detached\r\n" ESC_FG_WHITE));
}

// Event handler for the USB_DeviceEnumerationComplete event. This indicates that a device has been successfully
// enumerated by the host and is now ready to be used by the application.
void EVENT_USB_Host_DeviceEnumerationComplete(void)
{
	puts_P(PSTR("Getting configuration data from device...\r\n"));

	uint8_t ErrorCode;

	/* Get and process the configuration descriptor data */
	if ((ErrorCode = ProcessConfigurationDescriptor()) != SuccessfulConfigRead) {
		if (ErrorCode == ControlError) {
			puts_P(PSTR(ESC_FG_RED "Control Error (Get configuration)!\r\n"));
		} else {
			puts_P(PSTR(ESC_FG_RED "Invalid Device!\r\n"));
		}

		printf_P(PSTR(" -- Error Code: %d\r\n" ESC_FG_WHITE), ErrorCode);
		return;
	}

	// Set the device configuration to the first configuration (rarely do devices use multiple configurations)
	if ((ErrorCode = USB_Host_SetDeviceConfiguration(1)) != HOST_SENDCONTROL_Successful) {
		printf_P(PSTR(ESC_FG_RED "Control Error (Set configuration)!\r\n"
		                         " -- Error Code: %d\r\n" ESC_FG_WHITE), ErrorCode);
		return;
	}
	
	// HID class request to set the mouse protocol to the Boot Protocol
	USB_ControlRequest = (USB_Request_Header_t) {
			.bmRequestType = (REQDIR_HOSTTODEVICE | REQTYPE_CLASS | REQREC_INTERFACE),
			.bRequest      = HID_REQ_SetProtocol,
			.wValue        = 0,
			.wIndex        = 0,
			.wLength       = 0,
	};

	// Select the control pipe for the request transfer
	Pipe_SelectPipe(PIPE_CONTROLPIPE);

	// Send the request, display error and wait for device detach if request fails
	if ((ErrorCode = USB_Host_SendControlRequest(NULL)) != HOST_SENDCONTROL_Successful) {
		printf_P(PSTR(ESC_FG_RED "Control Error (Set protocol)!\r\n"
								 " -- Error Code: %d\r\n" ESC_FG_WHITE), ErrorCode);

		USB_Host_SetDeviceConfiguration(0);
		return;
	}

	puts_P(PSTR("USB Mouse enumeration successful\r\n"));
}

// Event handler for the USB_HostError event. This indicates that a hardware error occurred while in host mode.
void EVENT_USB_Host_HostError(const uint8_t ErrorCode)
{
	USB_Disable();

	printf_P(PSTR(ESC_FG_RED "Host Mode Error!\r\n"
	                       " -- Error Code %d\r\n" ESC_FG_WHITE), ErrorCode);

	while(1);
}
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

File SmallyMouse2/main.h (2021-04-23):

/************************************************************************
	main.h

	Main functions
    SmallyMouse2 - USB to quadrature mouse converter
    Copyright (C) 2017-2020 Simon Inns

	This file is part of SmallyMouse2.

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
	Email: simon.inns@gmail.com

************************************************************************/

#ifndef _MAIN_H_
#define _MAIN_H_

// Hardware map

// Quadrature mouse output port
// Right mouse button
#define RB_PORT	PORTC
#define RB_PIN	PINC
#define RB_DDR	DDRC
#define RB		(1 << 6)

// Middle mouse button
#define MB_PORT	PORTC
#define MB_PIN	PINC
#define MB_DDR	DDRC
#define MB		(1 << 5)

// Left mouse button
#define LB_PORT	PORTC
#define LB_PIN	PINC
#define LB_DDR	DDRC
#define LB		(1 << 4)

// Y axis output
#define Y2_PORT	PORTC
#define Y2_PIN	PINC
#define Y2_DDR	DDRC
#define Y2		(1 << 3)

#define Y1_PORT	PORTC
#define Y1_PIN	PINC
#define Y1_DDR	DDRC
#define Y1		(1 << 1)

// X axis output
#define X2_PORT	PORTC
#define X2_PIN	PINC
#define X2_DDR	DDRC
#define X2		(1 << 2)

#define X1_PORT	PORTC
#define X1_PIN	PINC
#define X1_DDR	DDRC
#define X1		(1 << 0)

// Rate limit on/off switch (marked 'slow')
/*
#define RATESW_PORT	PORTA
#define RATESW_PIN	PINA
#define RATESW_DDR	DDRA
#define RATESW		(1 << 4)
*/
#define RATESW_PORT	PORTD
#define RATESW_PIN	PIND
#define RATESW_DDR	DDRD
#define RATESW		(1 << 7)


// Expansion (Ian) header
#define E0_PORT	PORTD
#define E0_PIN	PIND
#define E0_DDR	DDRD
#define E0		(1 << 0)

#define E1_PORT	PORTD
#define E1_PIN	PIND
#define E1_DDR	DDRD
#define E1		(1 << 1)

#define E2_PORT	PORTD
#define E2_PIN	PIND
#define E2_DDR	DDRD
#define E2		(1 << 2)

#define E3_PORT	PORTD
#define E3_PIN	PIND
#define E3_DDR	DDRD
#define E3		(1 << 3)

#define E4_PORT	PORTD
#define E4_PIN	PIND
#define E4_DDR	DDRD
#define E4		(1 << 4)

#define E5_PORT	PORTD
#define E5_PIN	PIND
#define E5_DDR	DDRD
#define E5		(1 << 5)

#define E6_PORT	PORTD
#define E6_PIN	PIND
#define E6_DDR	DDRD
#define E6		(1 << 6)


// E7 is now used as the DPISW header
/*
#define DPISW_PORT	PORTD
#define DPISW_PIN	PIND
#define DPISW_DDR	DDRD
#define DPISW		(1 << 7)
*/
#define DPISW_PORT	PORTA
#define DPISW_PIN	PINA
#define DPISW_DDR	DDRA
#define DPISW		(1 << 4)


// Function prototypes
void initialiseHardware(void);
void initialiseTimers(void);
void processMouse(void);
uint8_t processMouseMovement(int8_t movementUnits, uint8_t axis, bool limitRate, bool dpiDivide);

// USB callback event handlers (LUFA)
void EVENT_USB_Host_HostError(const uint8_t ErrorCode);
void EVENT_USB_Host_DeviceAttached(void);
void EVENT_USB_Host_DeviceUnattached(void);
void EVENT_USB_Host_DeviceEnumerationFailed(const uint8_t ErrorCode, const uint8_t SubErrorCode);
void EVENT_USB_Host_DeviceEnumerationComplete(void);

void ReadNextReport(void);

#endif

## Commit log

2019-11-28 Adding the release version of Smalliermouse
    [smalliermouse.kicad_pcb, smalliermouse.sch]
2019-12-07 Added prescaler for DPI correction
    [main.c]
2019-12-31 Fixed DPISCALE logic -- introduced a skipped count to make sure the scaling works at very low levels.
    [main.c]
2021-04-23 Closing the gap between SmallierMouse and SmallyMouse2. To wit:
    * Taken latest source incorporating fixes to direction lag and my suggested scaling.
    * Set ST-optimised values for the divisor, quad limit and buffer
    * Added my sub-pixel divisor logic
    * Made rate limiting the default
    * Swapped the pins for the divisor and rate limit headers as SmallierMouse was designed before this header was available and frankly removing the limit is madness on an ST
    [main.c, main.h]
2021-04-29 Providing a couple of sample binaries ready for release 1.1

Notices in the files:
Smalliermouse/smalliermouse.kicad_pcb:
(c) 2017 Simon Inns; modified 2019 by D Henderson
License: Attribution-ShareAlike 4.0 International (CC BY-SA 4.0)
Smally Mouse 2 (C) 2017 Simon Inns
